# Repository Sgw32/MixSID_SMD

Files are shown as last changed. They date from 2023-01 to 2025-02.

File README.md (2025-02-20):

# MixSID - SMD version
*flexible Stereo-SID-board with integrated channel mixer*

The MixSID is a stereo SID board for the C64 that can be used with any combination 
of SID models on a wide range of C64 mainboards.

Features include an integrated stereo channel mixer, 
pragmatic stereo addressing scheme, flexible handling of io areas,
onboard audio input, output and digiboost circuits, 
dedicated stereo output, full paddle compatibility and versatile digital control.

For more information, please see the project page, available in both 
[english](http://www.henning-bekel.de/mixsid) and [german](http://www.henning-bekel.de/mixsid/de).

SMD version is fully compatible with original one from Henning Bekel, also it is licensed and released as a derivative using GPL license. 

GNU GENERAL PUBLIC LICENSE
Version 2, June 1991 (see more on project page)

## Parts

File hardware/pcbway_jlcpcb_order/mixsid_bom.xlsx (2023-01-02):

Comment | Designator | Footprint | JLCPCB Part #（optional）
74HC4053 | U7 | SOIC-16
100n | C27,C24,C14,C13,C26,C8,C6,C25,C23 | 0805
220k | R10,R1 | 0805
100k | R2,R9 | 0805
22n | C12,C10,C4,C2 | 0805
470p | C11,C9,C3,C1,C7,C5,C16,C21 | 0805
DF13-3P | P5 | DF13-3P
DF13-3P | P1 | DF13-5P
CJ7809 | U4 | TO-252-2 | C177737
CJ7812 | U3 | TO-252-2 | C26184
S1A | D2,D1 | DO-214AC
10u | C18,C17 | 0805
1k | R6,R14,R13,e1,R12,R5 | 0805
10k | R11,R4 | 0805
1n | C15,C20 | 0805
BCP54 | Q2,Q1 | SOT-223
74hc4052 | U6 | SOIC-16
10uF | C22,C19 | 0805
4k7 | R8,R7 | 0805
XL7660 | U8 | SOIC-8

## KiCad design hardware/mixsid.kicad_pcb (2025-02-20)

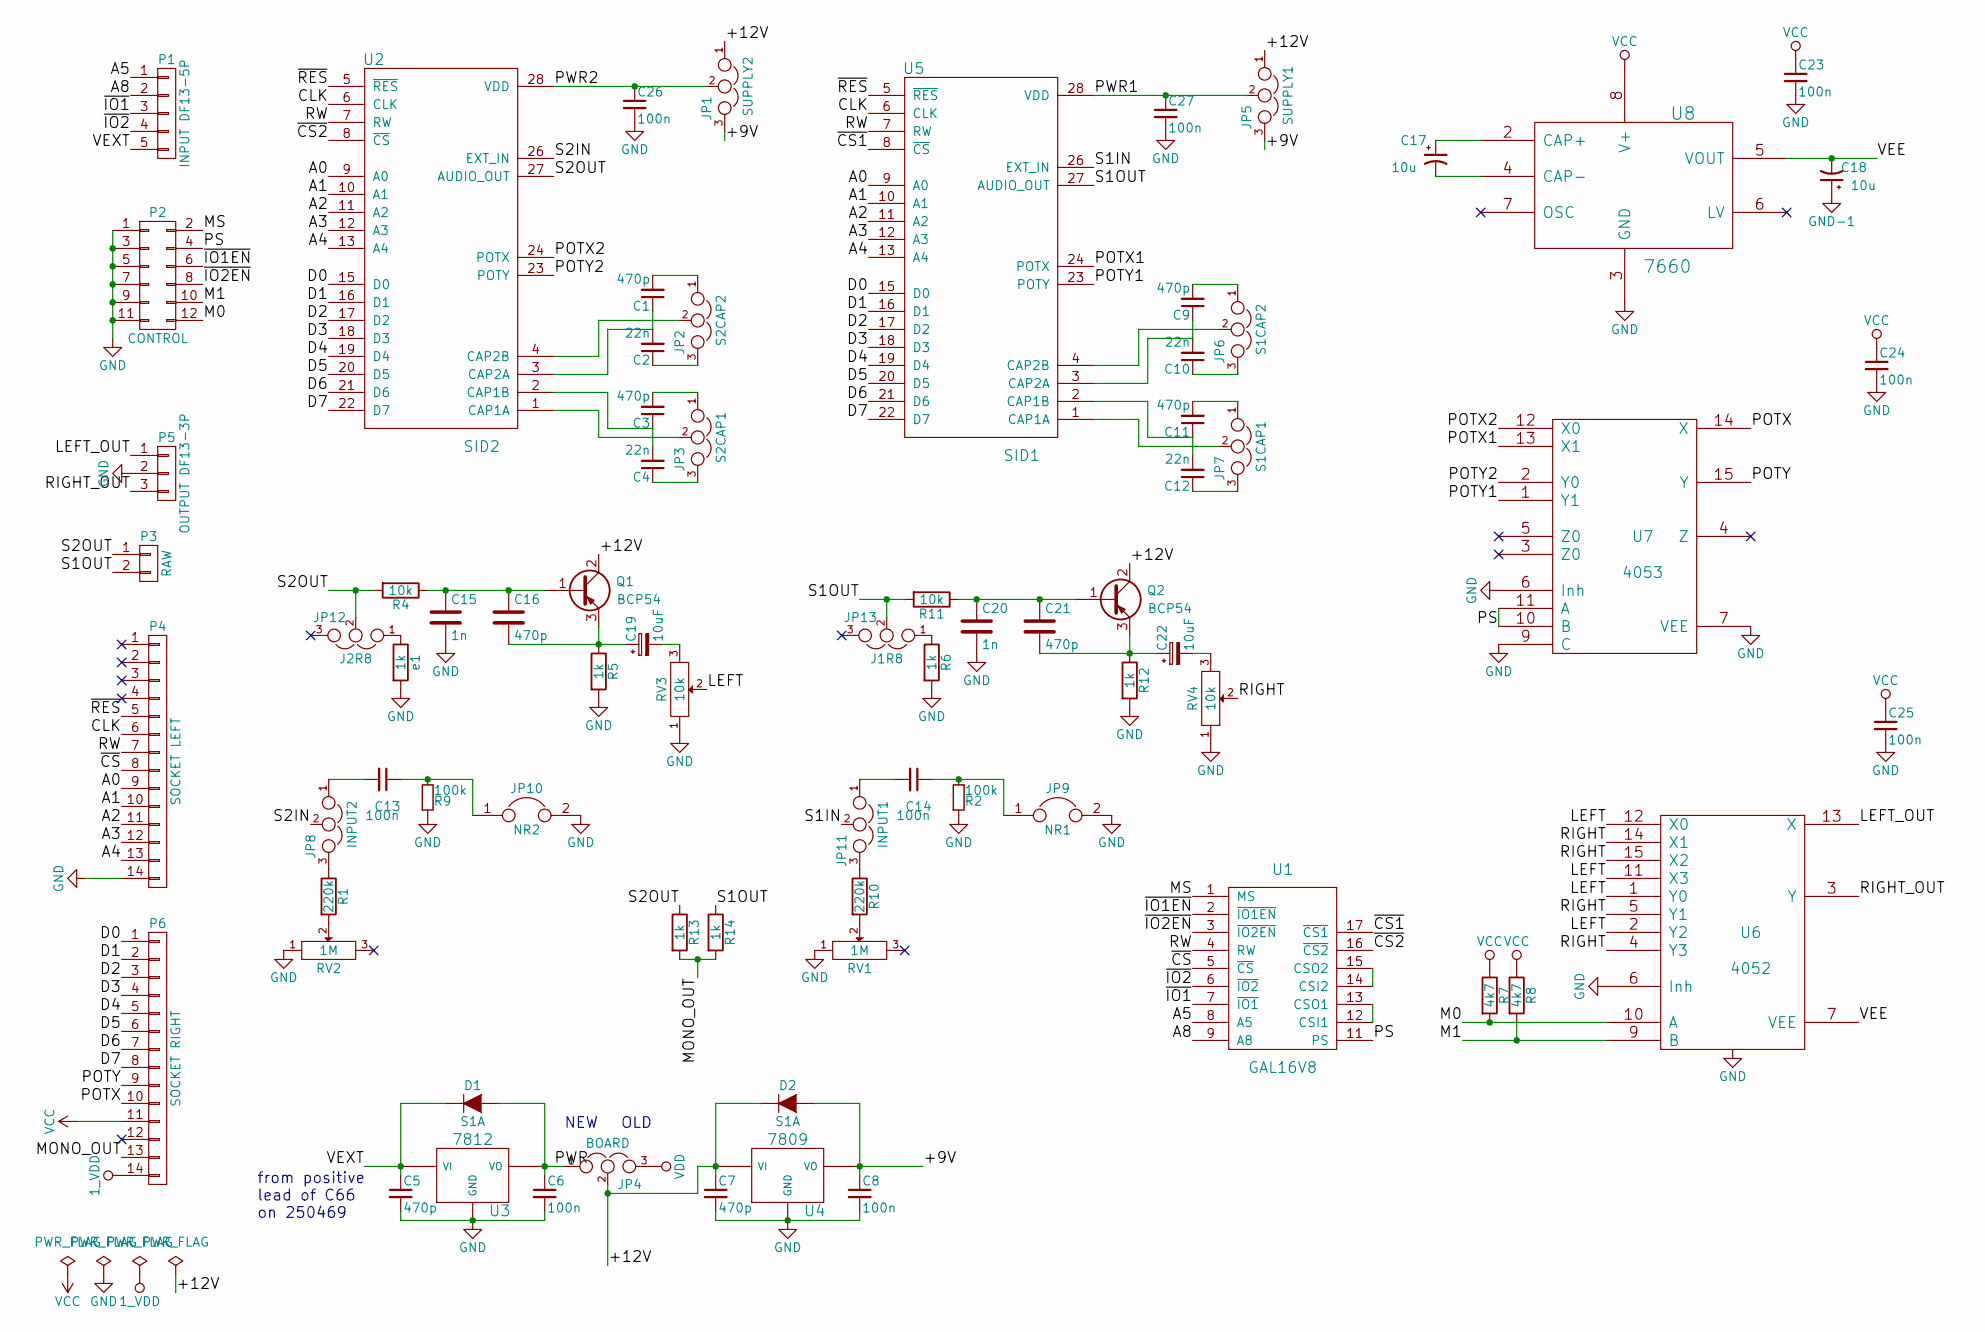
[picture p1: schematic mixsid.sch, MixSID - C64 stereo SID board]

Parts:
C1, C3, C5, C7, C9, C11, C16, C21: 470p; 0805
C2, C4, C10, C12: 22n; 0805
C6, C8, C13, C14, C23, C24, C25, C26, C27: 100n; 0805
C15, C20: 1n; 0805
C17, C18: 10u; 0805
C19, C22: 10uF; 0805
D1, D2: S1A; DO-214AC
JP1: SUPPLY2; Pin_Header_Straight_1x03_Pitch2.00mm
JP2: S2CAP2; Pin_Header_Straight_1x03_Pitch2.00mm
JP3: S2CAP1; Pin_Header_Straight_1x03_Pitch2.00mm
JP4: BOARD; Pin_Header_Straight_1x03
JP5: SUPPLY1; Pin_Header_Straight_1x03_Pitch2.00mm
JP6: S1CAP2; Pin_Header_Straight_1x03_Pitch2.00mm
JP7: S1CAP1; Pin_Header_Straight_1x03_Pitch2.00mm
JP8: INPUT2; Pin_Header_Straight_1x03_Pitch2.00mm
JP9: NR1; Pin_Header_Straight_1x02
JP10: NR2; Pin_Header_Straight_1x02
JP11: INPUT1; Pin_Header_Straight_1x03_Pitch2.00mm
JP12: J2R8; Pin_Header_Straight_1x03_Pitch2.00mm
JP13: J1R8; Pin_Header_Straight_1x03_Pitch2.00mm
P1: INPUT DF13-5P; DF13-5P
P2: CONTROL; Pin_Header_Straight_2x06
P3: RAW; Pin_Header_Straight_1x02
P4: SOCKET LEFT; Pin_Header_Straight_1x14
P5: OUTPUT DF13-3P; DF13-3P
P6: SOCKET RIGHT; Pin_Header_Straight_1x14
Q1, Q2: BCP54; SOT-223
R1, R10: 220k; 0805
R2, R9: 100k; 0805
R4, R11: 10k; 0805
R5, R6, R12, R13, R14: 1k; 0805
R7, R8: 4k7; 0805
RV1, RV2: 1M; Potentiometer_Bourns_3296W_3-8Zoll_Inline_ScrewUp
RV3, RV4: 10k; Potentiometer_Bourns_3339P_Angular_ScrewUp
U1: GAL16V8; DIP-20_W7.62mm
U2: SID2; DIP-28_W15.24mm
U3: 7812; TO-252-2
U4: 7809; TO-252-2
U5: SID1; DIP-28_W15.24mm
U6: 4052; SOIC-16
U7: 4053; SOIC-16
U8: 7660; SOIC-8
e1: 1k; 0805

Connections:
/+9V: C8.1, D2.2 (A), JP1.3, JP5.3, U4.3 (VO)
/+12V: C7.1, D2.1 (K), JP1.1, JP4.2, JP5.1, Q1.2 (C), Q2.2 (C), U4.1 (VI)
/A0: P4.9, U2.9 (A0), U5.9 (A0)
/A1: P4.10, U2.10 (A1), U5.10 (A1)
/A2: P4.11, U2.11 (A2), U5.11 (A2)
/A3: P4.12, U2.12 (A3), U5.12 (A3)
/A4: P4.13, U2.13 (A4), U5.13 (A4)
/A5: P1.1, U1.8 (A5)
/A8: P1.2, U1.9 (A8)
/CLK: P4.6, U2.6 (CLK), U5.6 (CLK)
/D0: P6.1, U2.15 (D0), U5.15 (D0)
/D1: P6.2, U2.16 (D1), U5.16 (D1)
/D2: P6.3, U2.17 (D2), U5.17 (D2)
/D3: P6.4, U2.18 (D3), U5.18 (D3)
/D4: P6.5, U2.19 (D4), U5.19 (D4)
/D5: P6.6, U2.20 (D5), U5.20 (D5)
/D6: P6.7, U2.21 (D6), U5.21 (D6)
/D7: P6.8, U2.22 (D7), U5.22 (D7)
/LEFT: RV3.2, U6.1 (Y0), U6.2 (Y2), U6.11 (X3), U6.12 (X0)
/LEFT_OUT: P5.1, U6.13 (X)
/M0: P2.12, R7.2, U6.10 (A)
/M1: P2.10, R8.2, U6.9 (B)
/MONO_OUT: P6.13, R13.2, R14.2
/MS: P2.2, U1.1 (MS)
/POTX: P6.10, U7.14 (X)
/POTX1: U5.24 (POTX), U7.13 (X1)
/POTX2: U2.24 (POTX), U7.12 (X0)
/POTY: P6.9, U7.15 (Y)
/POTY1: U5.23 (POTY), U7.1 (Y1)
/POTY2: U2.23 (POTY), U7.2 (Y0)
/PS: P2.4, U1.11 (PS), U7.10 (B), U7.11 (A)
/PWR: C6.1, D1.2 (A), JP4.1, U3.3 (VO)
/PWR1: C27.1, JP5.2, U5.28 (VDD)
/PWR2: C26.1, JP1.2, U2.28 (VDD)
/RIGHT: RV4.2, U6.4 (Y3), U6.5 (Y1), U6.14 (X1), U6.15 (X2)
/RIGHT_OUT: P5.3, U6.3 (Y)
/RW: P4.7, U1.4 (RW), U2.7 (RW), U5.7 (RW)
/S1IN: JP11.2, U5.26 (EXT_IN)
/S1OUT: JP13.2, P3.2, R11.2, R14.1, U5.27 (AUDIO_OUT)
/S2IN: JP8.2, U2.26 (EXT_IN)
/S2OUT: JP12.2, P3.1, R4.2, R13.1, U2.27 (AUDIO_OUT)
/VEE: C18.2, U6.7 (VEE), U8.5 (VOUT)
/VEXT: C5.1, D1.1 (K), P1.5, U3.1 (VI)
/~CS1: U1.17 (~CS1), U5.8 (~CS)
/~CS2: U1.16 (~CS2), U2.8 (~CS)
/~CS: P4.8, U1.5 (~CS)
/~IO1EN: P2.6, U1.2 (~IO1EN)
/~IO1: P1.3, U1.7 (~IO1)
/~IO2EN: P2.8, U1.3 (~IO2EN)
/~IO2: P1.4, U1.6 (~IO2)
/~RES: P4.5, U2.5 (~RES), U5.5 (~RES)
unnamed: C1.1, C2.2, U2.3 (CAP2A)
unnamed: C1.2, JP2.1
unnamed: C2.1, JP2.3
unnamed: C3.1, C4.2, U2.2 (CAP1B)
unnamed: C3.2, JP3.1
unnamed: C4.1, JP3.3
unnamed: C9.2, JP6.1
unnamed: C10.1, JP6.3
unnamed: C9.1, C10.2, U5.3 (CAP2A)
unnamed: C11.1, C12.2, U5.2 (CAP1B)
unnamed: C11.2, JP7.1
unnamed: C12.1, JP7.3
unnamed: C13.1, JP10.1, R9.2
unnamed: C13.2, JP8.1
unnamed: C14.1, JP9.1, R2.2
unnamed: C14.2, JP11.1
unnamed: C15.1, C16.1, Q1.1 (B), R4.1
unnamed: C16.2, C19.1, Q1.3 (E), R5.1
unnamed: C17.1, U8.2 (CAP+)
unnamed: C17.2, U8.4 (CAP-)
unnamed: C19.2, RV3.3
unnamed: C20.1, C21.1, Q2.1 (B), R11.1
unnamed: C21.2, C22.1, Q2.3 (E), R12.1
unnamed: C22.2, RV4.3
unnamed: JP2.2, U2.4 (CAP2B)
unnamed: JP3.2, U2.1 (CAP1A)
unnamed: JP6.2, U5.4 (CAP2B)
unnamed: JP7.2, U5.1 (CAP1A)
unnamed: JP8.3, R1.1
unnamed: JP11.3, R10.1
unnamed: JP12.1, e1.1
unnamed: JP13.1, R6.1
unnamed: R1.2, RV2.2
unnamed: R10.2, RV1.2
unnamed: U1.12 (CSI1), U1.13 (CSO1)
unnamed: U1.14 (CSI2), U1.15 (CSO2)
VCC: C23.1, C24.1, C25.1, P6.11, R7.1, R8.1, U1.20 (VCC), U2.25 (VCC), U5.25 (VCC), U6.16 (VCC), U7.16 (VCC), U8.8 (V+)

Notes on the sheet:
NEW
OLD
from positive lead of C66 on 250469

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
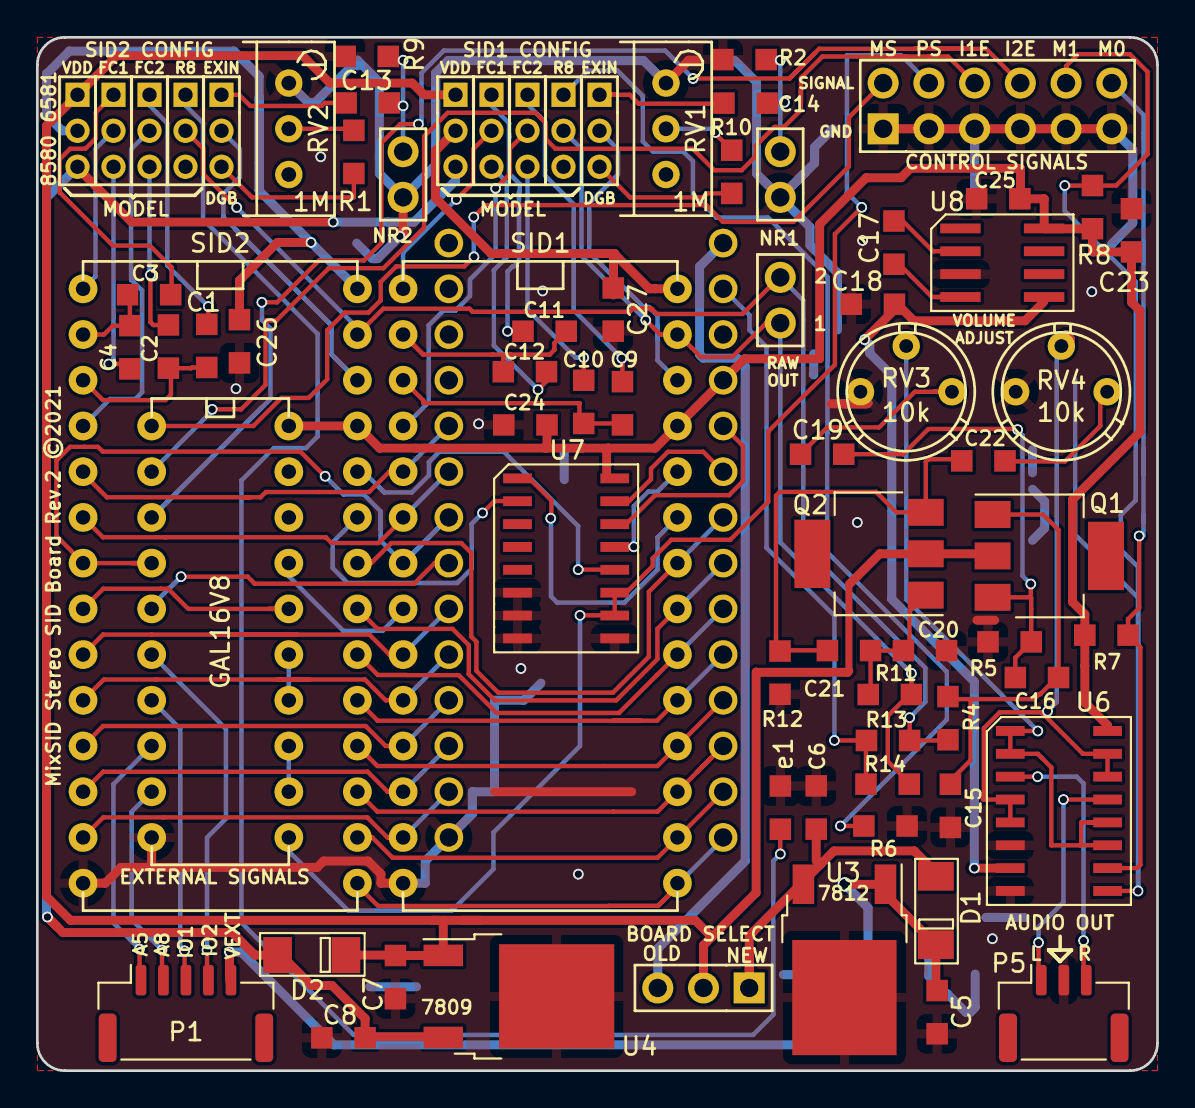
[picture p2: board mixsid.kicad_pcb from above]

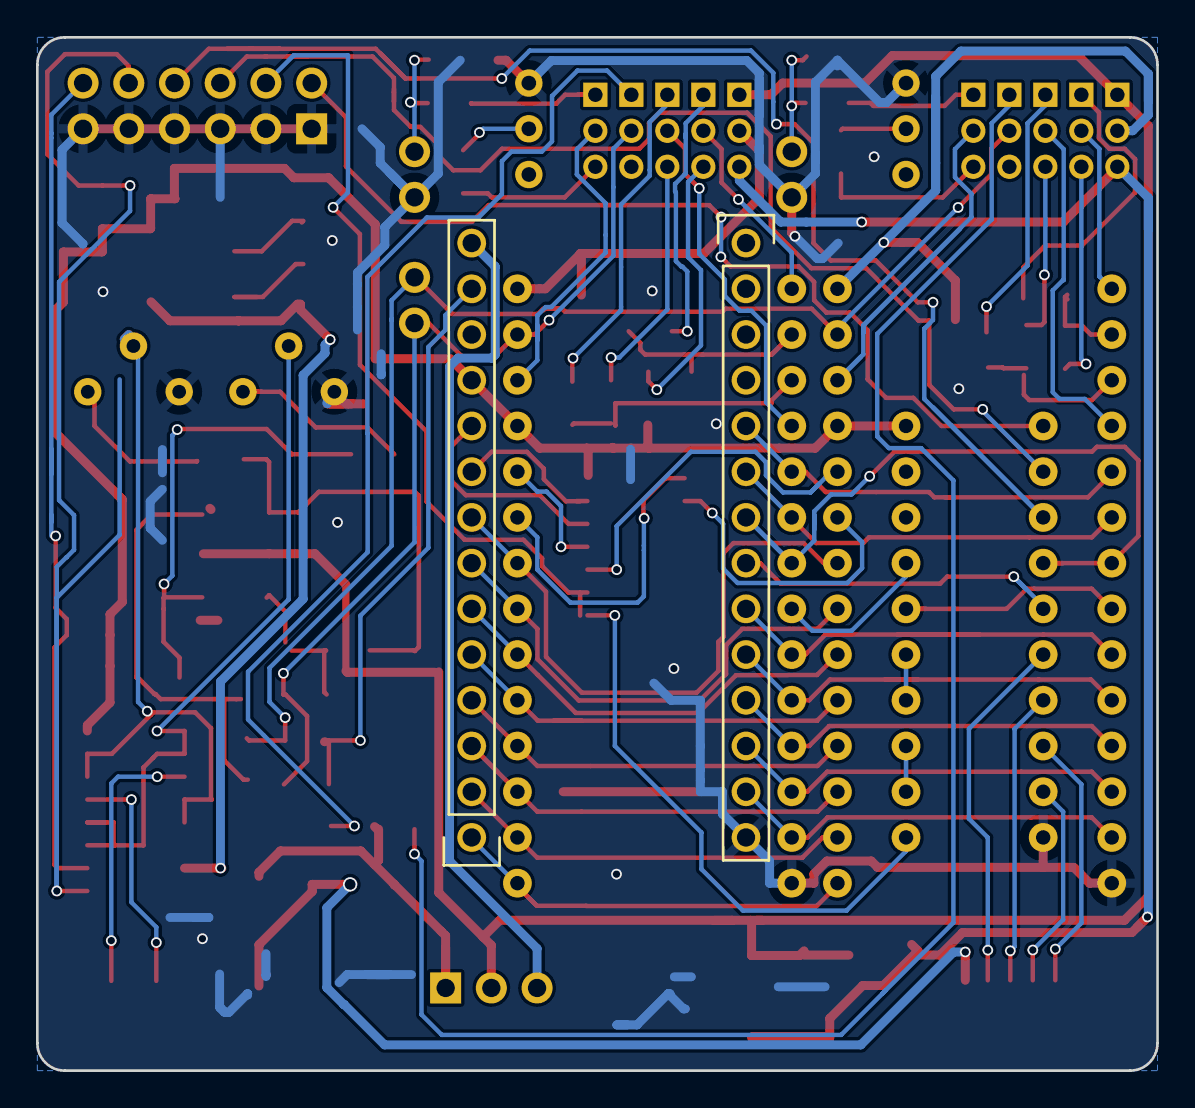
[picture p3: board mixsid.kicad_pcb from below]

Board: 2 copper layers, 62.2 x 57.4 mm, 76 parts (2 on the bottom side), 90 nets.

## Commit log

2023-01-02 Order files
    [mixsid_bom.xlsx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]
2025-02-20 Adjust connectors to match JST GH
    [mixsid.kicad_pcb]

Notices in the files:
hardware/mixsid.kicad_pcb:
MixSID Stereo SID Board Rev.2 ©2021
